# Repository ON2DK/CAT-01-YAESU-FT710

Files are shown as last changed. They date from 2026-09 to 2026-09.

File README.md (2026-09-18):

# CAT-01 YAESU FT-710

CAT-01 is a radio-specific CAT interface for connecting the **ESP32 CW Keyer V2** universal 3.3 V UART CAT port to the **Yaesu FT-710 CAT-3** interface.

> **Project status:** PCB production files completed. Hardware testing with the assembled PCB and FT-710 is still pending.

## Purpose

The ESP32 CW Keyer V2 uses 3.3 V UART levels on its universal CAT connector. The FT-710 CAT-3 interface uses 5 V TTL levels. CAT-01 provides the required interface between both devices.

The design uses an **SN74HCT125N** powered from 5 V for the Keyer-to-radio path and a resistor divider for the radio-to-Keyer path.

## Connections

### J1 — KEYER_CAT

| Signal | Function |
|---|---|
| +5V | Power for CAT-01 |
| KEYER_RX_3V3 | CAT data from radio to Keyer |
| KEYER_TX_3V3 | CAT data from Keyer to radio |
| GND | Ground |

Always follow the **signal names printed on the final PCB silkscreen** when wiring the connector.

### J2 — FT-710 CAT-3

| CAT-01 signal | FT-710 TUNER/LINEAR CAT-3 connection |
|---|---|
| GND | Pin 3 — GND |
| FT710_TXD_5V | Pin 4 — TXD from FT-710 |
| FT710_RXD_5V | Pin 5 — RXD to FT-710 |

**Important:** FT-710 TUNER/LINEAR **pin 1 (+13 V) must not be connected to CAT-01**.

## Signal paths

**Keyer → FT-710**

`KEYER_TX_3V3 → SN74HCT125N → R3 100 Ω → FT710_RXD_5V → FT-710`

**FT-710 → Keyer**

`FT710_TXD_5V → R1/R2 level divider → KEYER_RX_3V3 → ESP32 CW Keyer V2`

## Main components

| Reference | Value / type |
|---|---|
| U1 | SN74HCT125N, DIP-14 |
| C1 | 100 nF |
| R1 | 10 kΩ |
| R2 | 20 kΩ |
| R3 | 100 Ω |
| R4 | 1 kΩ |
| D1 | Power LED |

## Repository layout

The project will contain:

- `KiCad/` — editable KiCad schematic, PCB and project files
- `Gerbers/` — final manufacturing Gerber/drill package
- `Documentation/` — connection and production documentation
- `Photos/` — photographs of the assembled/tested adapter when available

## Manufacturing status

The final KiCad design was checked with:

- 0 DRC violations
- 0 unconnected items
- 0 schematic parity issues

A final visual PCB inspection was also performed and the routing near a via was corrected before regenerating the manufacturing files.

The Gerber package includes front/back copper, front/back solder mask, front/back silkscreen, Edge.Cuts, PTH drill, NPTH drill and Gerber job data.

## Hardware verification

The PCB has been sent for manufacture. The design should therefore currently be treated as **production files completed / hardware test pending**.

After the first assembled CAT-01 has been tested with the ESP32 CW Keyer V2 and a Yaesu FT-710, this section will be updated with the measured/test results and photographs.

## Related project

CAT-01 is intended to be used with the **ESP32 CW Keyer V2**. The Keyer keeps a universal CAT connector so that separate radio-specific adapters can be developed without changing the complete Keyer PCB.

## Disclaimer

This is an amateur-radio DIY hardware project. Verify connector pinout, supply voltage and signal levels before connecting the adapter to a transceiver. In particular, do not connect the FT-710 +13 V pin to CAT-01.

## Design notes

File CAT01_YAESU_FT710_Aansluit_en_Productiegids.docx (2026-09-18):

# CAT-01 YAESU FT-710 Aansluit- en productiegids

Adapter voor ESP32 CW KEYER V2 • 3.3 V ↔ 5 V TTL CAT

# 1. Doel

CAT-01 is de radio-specifieke adapter tussen de universele 3.3 V CAT-aansluiting van de ESP32 CW KEYER V2 en de CAT-3 aansluiting van de Yaesu FT-710. De print gebruikt een SN74HCT125N als buffer/level-interface.

# 2. Connector J1 – KEYER_CAT

J1 pin | Signaal | Functie
1 | +5V | Voeding voor CAT-01
2 | KEYER_RX_3V3 | RX-signaal naar de keyer
3 | KEYER_TX_3V3 | TX-signaal van de keyer
4 | GND | Massa

# 3. Connector J2 – FT-710 CAT-3

J2 pin | Net op CAT-01 | Bestemming FT-710
1 | FT710_RXD_5V | CAT-3 pin 5 – RXD van de FT-710
2 | FT710_TXD_5V | CAT-3 pin 4 – TXD van de FT-710
3 | GND | CAT-3 pin 3 – GND

BELANGRIJK: FT-710 CAT-3 pin 1 (+13 V) wordt NIET aangesloten op CAT-01.

# 4. Signaalrichting

Keyer TX: KEYER_TX_3V3 → U1 → FT710_RXD_5V → FT-710 CAT-3 pin 5.
Radio TX: FT-710 CAT-3 pin 4 → FT710_TXD_5V → R1/R2-interface → KEYER_RX_3V3 → keyer.

# 5. Onderdelen op CAT-01

Ref. | Waarde / type | Opmerking
U1 | SN74HCT125N | DIP-14 quad HCT tri-state buffer
C1 | 100 nF | Ontkoppeling tussen +5 V en GND, dicht bij U1
R1 | 10 kΩ | RX niveau-interface
R2 | 20 kΩ | RX niveau-interface
R3 | 100 Ω | Serieweerstand BUF_OUT → FT710_RXD_5V
R4 | 1 kΩ | Serieweerstand voor POWER LED
D1 | POWER LED | Pad 2 = A (anode), pad 1 = K (kathode/GND)

# 6. Montage en eerste test

Controleer vóór aansluiting op de radio de polariteit van D1, de oriëntatie van U1 (DIP-14 inkeping/pin 1), de voedingsspanning +5 V en continuïteit naar GND. Controleer daarna de verbindingen van J1 en J2 met een multimeter. Sluit de FT-710 pas aan nadat is bevestigd dat er nergens +5 V of +13 V op een 3.3 V keyer-signaal staat.

# 7. Productiestatus

KiCad eindcontrole: DRC 0 overtredingen, 0 niet-verbonden items en 0 schemapariteitsmeldingen. De definitieve Gerber-export bevat beide koperlagen, beide soldeermaskerlagen, beide silkscreenlagen, Edge.Cuts, PTH- en NPTH-boorbestanden en het Gerber-jobbestand.

Productiebestand | Aanwezig
CAT01_YAESU_FT710-F_Cu.gbr | Ja
CAT01_YAESU_FT710-B_Cu.gbr | Ja
CAT01_YAESU_FT710-F_Mask.gbr | Ja
CAT01_YAESU_FT710-B_Mask.gbr | Ja
CAT01_YAESU_FT710-f_Silkscreen.gbr | Ja
CAT01_YAESU_FT710-b_Silkscreen.gbr | Ja
CAT01_YAESU_FT710-Edge_Cuts.gbr | Ja
CAT01_YAESU_FT710-PTH.drl | Ja
CAT01_YAESU_FT710-NPTH.drl | Ja
CAT01_YAESU_FT710-job.gbrjob | Ja

# 8. Projectnotitie

CAT-01 is specifiek bedoeld voor de Yaesu FT-710 CAT-3 interface. De universele CAT-aansluiting van de ESP32 CW KEYER V2 blijft een 3.3 V UART-interface; andere radio's kunnen een andere radio-specifieke adapter nodig hebben.

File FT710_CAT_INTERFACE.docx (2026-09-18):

Voor de FT-710 stel je daarna in:

OPERATION SETTING → GENERAL → TUN/LIN PORT SELECT → CAT-3

en voorlopig:

CAT-3 RATE = 38400
CAT-1 CAT-3 STOP BIT = 1
8 data bits
Parity = None

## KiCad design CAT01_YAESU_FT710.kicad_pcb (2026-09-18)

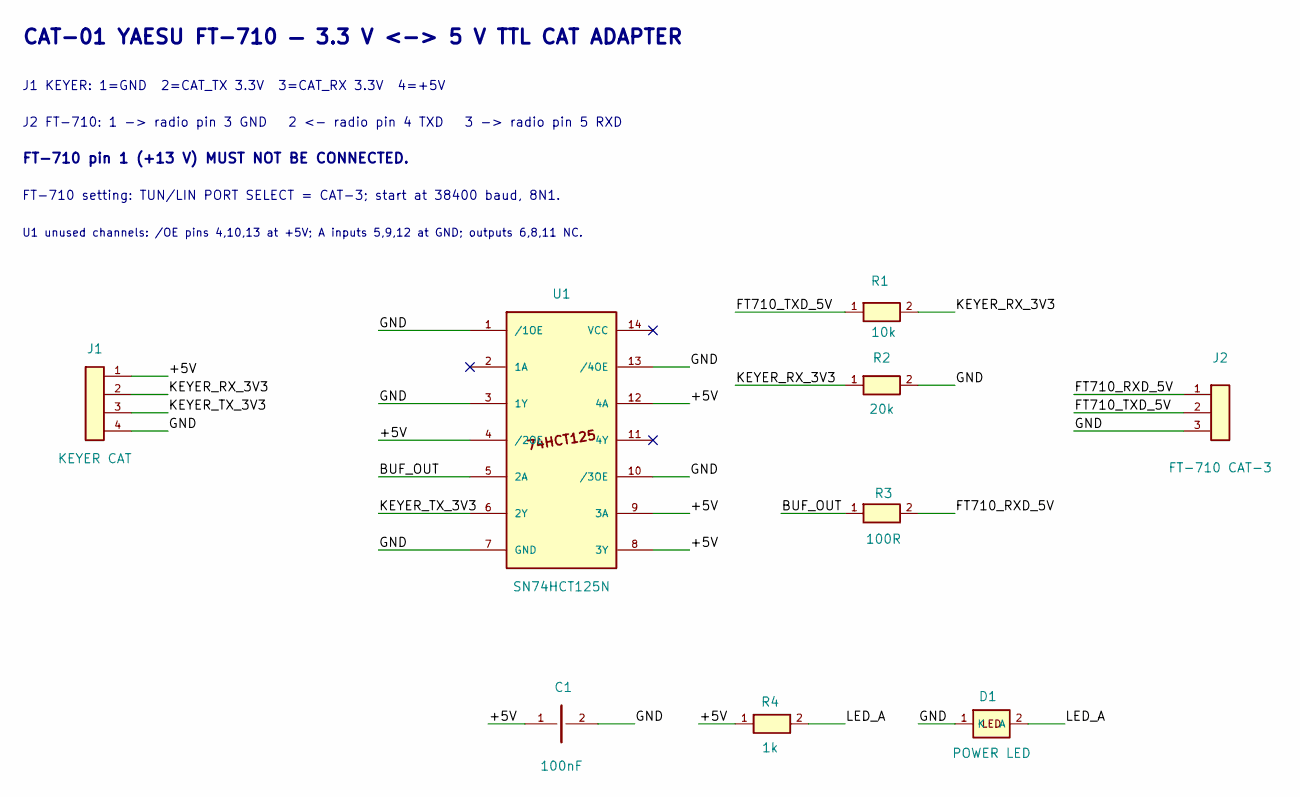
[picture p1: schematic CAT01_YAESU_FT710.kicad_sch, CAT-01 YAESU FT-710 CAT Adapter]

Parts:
C1: 100nF; C_DISC_3
D1: POWER LED; LED_4
J1: KEYER CAT; J1_4P
J2: FT-710 CAT-3; J2_3P
R1: 10k; R_AXIAL_10
R2: 20k; R_AXIAL_10
R3: 100R; R_AXIAL_10
R4: 1k; R_AXIAL_10
U1: SN74HCT125N; DIP14_762

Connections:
/+5V: C1.1, J1.1, R4.1, U1.4 (/2OE), U1.8 (3Y), U1.9 (3A), U1.12 (4A)
/BUF_OUT: R3.1, U1.5 (2A)
/FT710_RXD_5V: J2.1, R3.2
/FT710_TXD_5V: J2.2, R1.1
/GND: C1.2, D1.1 (K), J1.4, J2.3, R2.2, U1.1 (/1OE), U1.3 (1Y), U1.7 (GND), U1.10 (/3OE), U1.13 (/4OE)
/KEYER_RX_3V3: J1.2, R1.2, R2.1
/KEYER_TX_3V3: J1.3, U1.6 (2Y)
/LED_A: D1.2 (A), R4.2

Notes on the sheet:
U1 unused channels: /OE pins 4,10,13 at +5V; A inputs 5,9,12 at GND; outputs 6,8,11 NC.
J2 FT-710: 1 -> radio pin 3 GND 2 <- radio pin 4 TXD 3 -> radio pin 5 RXD
CAT-01 YAESU FT-710 — 3.3 V <-> 5 V TTL CAT ADAPTER
J1 KEYER: 1=GND 2=CAT_TX 3.3V 3=CAT_RX 3.3V 4=+5V
FT-710 pin 1 (+13 V) MUST NOT BE CONNECTED.
FT-710 setting: TUN/LIN PORT SELECT = CAT-3; start at 38400 baud, 8N1.

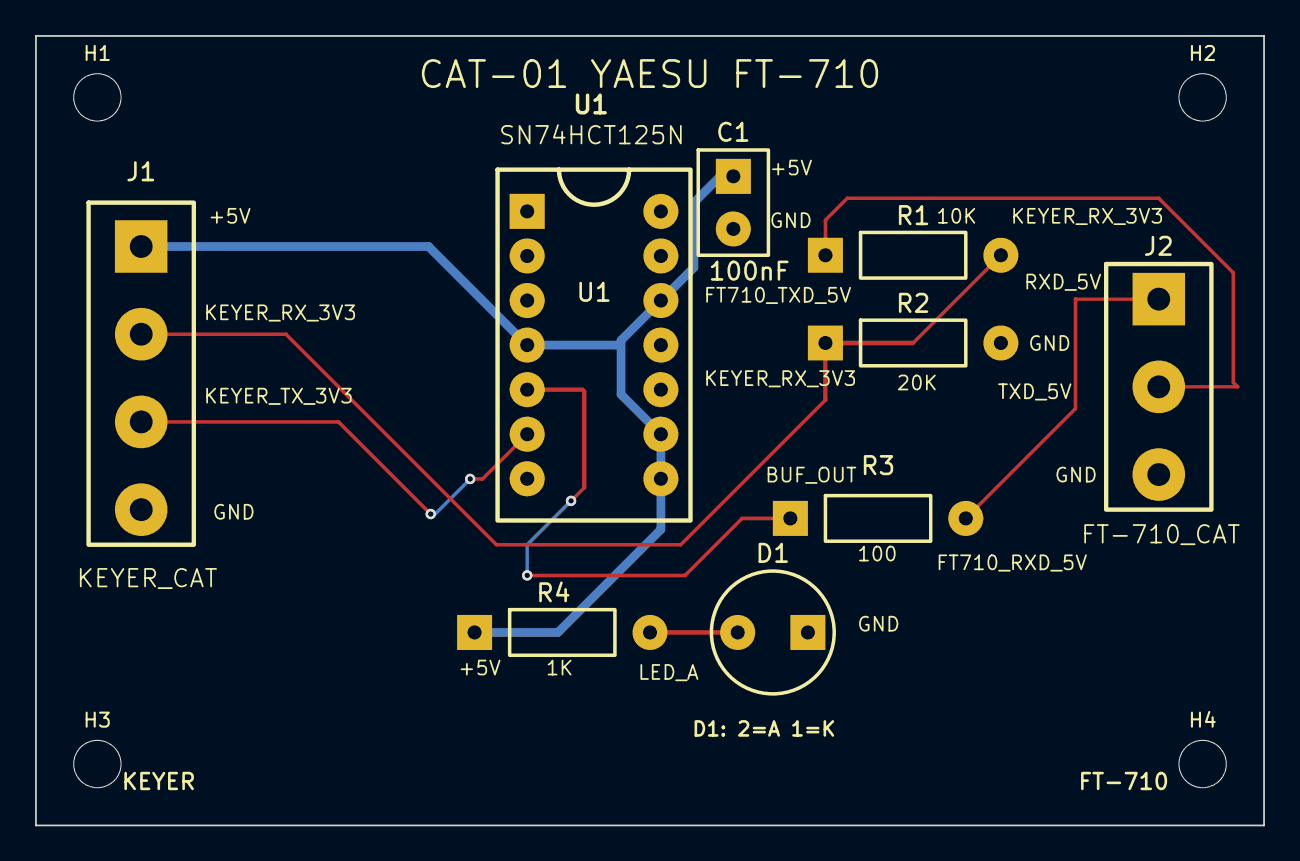
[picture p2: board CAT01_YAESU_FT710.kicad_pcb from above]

Board: 2 copper layers, 70.0 x 45.0 mm, 13 parts (0 on the bottom side), 8 nets.

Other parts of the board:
H1, H2, H3, H4: M2.5; MOUNT_M2_5
